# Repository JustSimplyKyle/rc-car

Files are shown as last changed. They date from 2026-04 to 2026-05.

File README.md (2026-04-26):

# Project Description
## tl;dr
a esp-32 powered rc-car, with a step-motor serving as its primary transmission force, using belt wheels for synchronzied left-right wheel, utilizing a mg996r for turning curcuits, displaying all infos on a 128x64 oled display, finally using 3d-printed parts for the car assembly

the pcb is designed using KiCad, while we use Rhino for 3d modeling software.
## why
our school hosted a simple car competition, a really simple one where there's just TT-motors wired to a wireless controller.
my friend and i had so much issues with that car, that we decided we want to make a new-and-improved:tm: version of it!
## wiring diagarm
## screenshots
|  |  |
| :---: | :---: |
| *(pcb layout)* | *(3d view)* |

| Image | Description |
| :---: | :--- |
|  | *(schematic)* |

# Project Structure
the root of the project contains the setup of the firmware, written in esp32-rust.
- `src/bin` - the actual production code for the esp32
- `src/motor` - all the motor control codes are extraplated in here, with mostly complete compile time checking so that timer usage aren't checked at runtime
- `src/ps2.rs & src/ps2_controller_task.rs` - the controller reception api
- `setup` - the pcb & schemcatic(kicad)
- `3d_models` - the 3d models

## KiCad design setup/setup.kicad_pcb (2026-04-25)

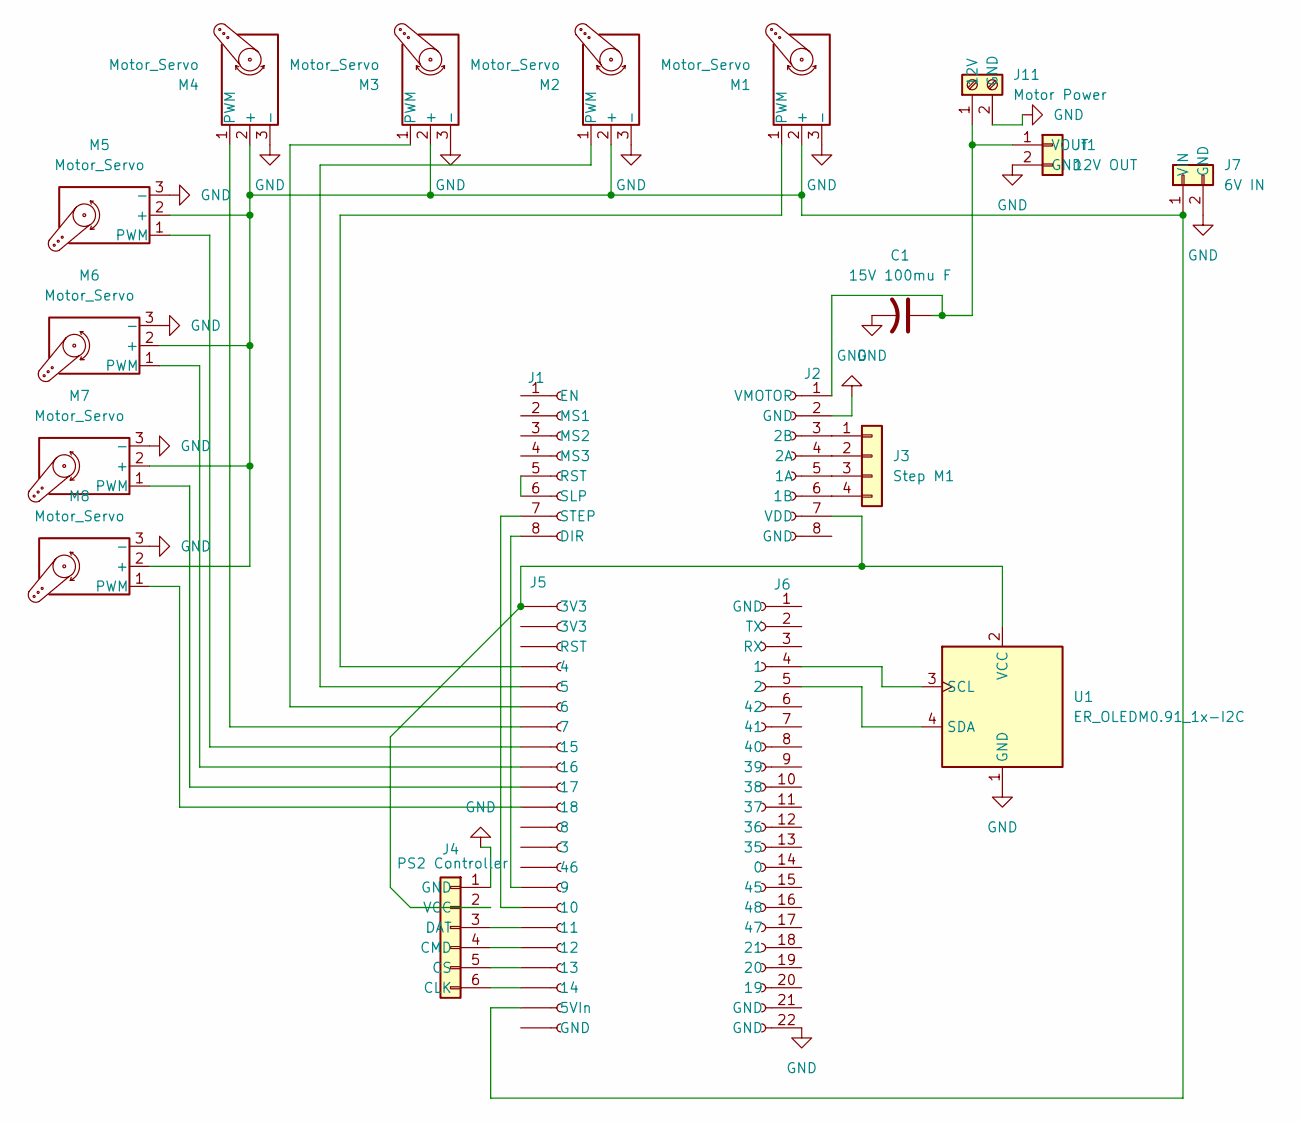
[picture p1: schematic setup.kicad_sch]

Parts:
C1: 15V 100mu F; C_Radial_D10.0mm_H12.5mm_P5.00mm
J1, J2: Conn_01x08_Socket; PinSocket_1x08_P2.54mm_Vertical
J3: Step M1; JST_PH_B4B-PH-K_1x04_P2.00mm_Vertical
J4: PS2 Controller; JST_PH_B6B-PH-K_1x06_P2.00mm_Vertical
J5, J6: Conn_01x22_Socket; PinSocket_1x22_P2.54mm_Vertical
J7: 6V IN; JST_VH_B2P-VH-FB-B_1x02_P3.96mm_Vertical
J11: Motor Power; JST_VH_B2P-VH-FB-B_1x02_P3.96mm_Vertical
Jf1: 12V OUT; JST_VH_B2P-VH-FB-B_1x02_P3.96mm_Vertical
M1, M2, M3, M4, M5, M6, M7, M8: Motor_Servo; JST_PH_B3B-PH-K_1x03_P2.00mm_Vertical
U1: ER_OLEDM0.91_1x-I2C; JST_XH_S4B-XH-A-1_1x04_P2.50mm_Horizontal

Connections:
GND: C1.2, J2.2 (GND), J4.1 (GND), J6.22 (GND), J7.2 (GND), J11.2 (GND), Jf1.2 (GND), M1.3 (-), M2.3 (-), M3.3 (-), M4.3 (-), M5.3 (-), M6.3 (-), M7.3 (-), M8.3 (-), U1.1 (GND)
unnamed: J1.8 (DIR), J5.15 (9)
unnamed: J1.5 (RST), J1.6 (SLP)
unnamed: J1.7 (STEP), J5.16 (10)
unnamed: J2.5 (1A), J3.3
unnamed: J2.6 (1B), J3.4
unnamed: J2.4 (2A), J3.2
unnamed: J2.3 (2B), J3.1
unnamed: J2.7 (VDD), J4.2 (VCC), J5.1 (3V3), U1.2 (VCC)
unnamed: J4.6 (CLK), J5.20 (14)
unnamed: J4.4 (CMD), J5.18 (12)
unnamed: J4.5 (CS), J5.19 (13)
unnamed: J4.3 (DAT), J5.17 (11)
unnamed: J5.21 (5VIn), J7.1 (VIN), M1.2 (+), M2.2 (+), M3.2 (+), M4.2 (+), M5.2 (+), M6.2 (+), M7.2 (+), M8.2 (+)
unnamed: J5.8 (15), M5.1 (PWM)
unnamed: J5.9 (16), M6.1 (PWM)
unnamed: J5.10 (17), M7.1 (PWM)
unnamed: J5.11 (18), M8.1 (PWM)
unnamed: J6.4 (1), U1.3 (SCL)
unnamed: J6.5 (2), U1.4 (SDA)
unnamed: C1.1, J2.1 (VMOTOR), J11.1 (12V), Jf1.1 (VOUT)
unnamed: J5.4, M1.1 (PWM)
unnamed: J5.5, M2.1 (PWM)
unnamed: J5.6, M3.1 (PWM)
unnamed: J5.7, M4.1 (PWM)

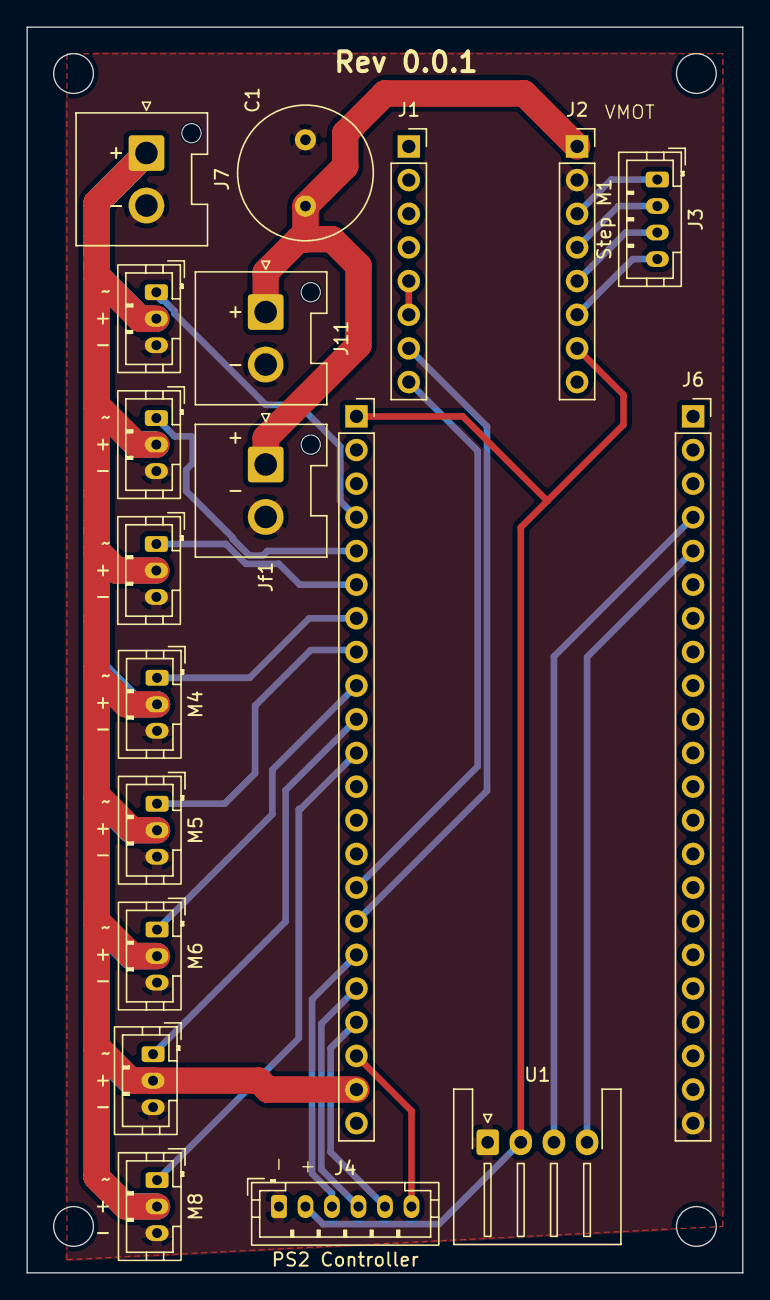
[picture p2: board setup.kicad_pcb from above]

Board: 4 copper layers, 54.0 x 94.0 mm, 19 parts (0 on the bottom side), 25 nets.

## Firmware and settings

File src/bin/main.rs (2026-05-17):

#![no_std]
#![feature(impl_trait_in_assoc_type, type_alias_impl_trait)]
#![no_main]

extern crate alloc;
extern crate rc_car;

use cobs::CobsDecoder;
use core::fmt::Write;
use defmt::error;
use defmt::warn;
use embassy_sync::blocking_mutex::raw::NoopRawMutex;
use embassy_sync::channel::Sender;
use embassy_sync::watch::Watch;
use embassy_time::Duration;
use esp_hal::interrupt::software::SoftwareInterruptControl;
use esp_hal::system::Stack;
use esp_hal::Async;
use esp_radio::esp_now::BROADCAST_ADDRESS;
use heapless::String;

use embedded_hal_compat::ReverseCompat;

use defmt::info;
use esp_hal::i2c::master::Config as I2cConfig;
use esp_hal::i2c::master::I2c;
use esp_hal::time::Rate;

use sh1106::{prelude::*, Builder};

use embassy_executor::Spawner;
use embassy_futures::select::{self, select};
use embassy_sync::blocking_mutex::raw::CriticalSectionRawMutex;
use embassy_time::Timer;
use embedded_graphics::{
    mono_font::{ascii::FONT_5X8, MonoTextStyleBuilder},
    pixelcolor::BinaryColor,
    prelude::Point,
    prelude::*,
    text::{Baseline, Text},
};
use esp_backtrace as _;
use esp_hal::ledc::{self, Ledc};
use esp_hal::{clock::CpuClock, delay::Delay, timer::timg::TimerGroup};
use esp_println as _;
use esp_rtos::start_second_core_with_stack_guard_offset;
use rc_car::motor::{self, ServoCmd};
use rc_car::ps2::Ps2Controller;
use rc_car::ps2_controller_task::PS2_GAMEPAD;
use static_cell::{make_static, StaticCell};

use defmt::println;

esp_bootloader_esp_idf::esp_app_desc!();

#[derive(Clone, Copy, Default)]
struct DisplayState {
    angles: [u32; 5],
}

#[repr(C)]
#[derive(Debug, Default, Copy, Clone)]
pub struct uni_gamepad_t {
    pub dpad: u8,
    pub axis_x: i32,
    pub axis_y: i32,
    pub axis_rx: i32,
    pub axis_ry: i32,
    pub brake: i32,
    pub throttle: i32,
    pub buttons: u16,
    pub misc_buttons: u8,
    pub gyro: [i32; 3usize],
    pub accel: [i32; 3usize],
}

impl uni_gamepad_t {
    pub fn pressed(&self, btn: Button) -> bool {
        match btn {
            Button::Dpad(dpad_direction) => {
                let id = match dpad_direction {
                    DpadDirection::Up => DPAD_UP,
                    DpadDirection::Down => DPAD_DOWN,
                    DpadDirection::Right => DPAD_RIGHT,
                    DpadDirection::Left => DPAD_LEFT,
                };
                (self.dpad & id) != 0
            }
            Button::Regular(btn) => {
                let id = match btn {
                    RegularButton::A => BUTTON_A,
                    RegularButton::B => BUTTON_B,
                    RegularButton::X => BUTTON_X,
                    RegularButton::Y => BUTTON_Y,
                    RegularButton::L1 => BUTTON_SHOULDER_L,
                    RegularButton::R1 => BUTTON_SHOULDER_R,
                    RegularButton::L2 => BUTTON_TRIGGER_L,
                    RegularButton::R2 => BUTTON_TRIGGER_R,
                    RegularButton::ThumbL => BUTTON_THUMB_L,
                    RegularButton::ThumbR => BUTTON_THUMB_R,
                };

                (self.buttons & id) != 0
            }
        }
    }
    pub fn status(&self) -> heapless::String<128> {
        use core::fmt::Write;
        use heapless::String;

        let mut out: String<128> = String::new();

        // D-Pad
        if self.pressed(Button::Dpad(DpadDirection::Up)) {
            let _ = write!(out, "UP ");
        }
        if self.pressed(Button::Dpad(DpadDirection::Down)) {
            let _ = write!(out, "DOWN ");
        }
        if self.pressed(Button::Dpad(DpadDirection::Left)) {
            let _ = write!(out, "LEFT ");
        }
        if self.pressed(Button::Dpad(DpadDirection::Right)) {
            let _ = write!(out, "RIGHT ");
        }

        // Face buttons + shoulders
        let checks = [
            (Button::Regular(RegularButton::A), "A"),
            (Button::Regular(RegularButton::B), "B"),
            (Button::Regular(RegularButton::X), "X"),
            (Button::Regular(RegularButton::Y), "Y"),
            (Button::Regular(RegularButton::L1), "L1"),
            (Button::Regular(RegularButton::R1), "R1"),
            (Button::Regular(RegularButton::L2), "L2"),
            (Button::Regular(RegularButton::R2), "R2"),
            (Button::Regular(RegularButton::ThumbL), "L3"),
            (Button::Regular(RegularButton::ThumbR), "R3"),
        ];

        for (btn, name) in checks {
            if self.pressed(btn) {
                let _ = write!(out, "{} ", name);
            }
        }

        // Optional: include analog hints (only if meaningful)
        if self.axis_x != 0 || self.axis_y != 0 {
            let _ = write!(out, "| LX:{} LY:{} ", self.axis_x, self.axis_y);
        }
        if self.axis_rx != 0 || self.axis_ry != 0 {
            let _ = write!(out, "| RX:{} RY:{} ", self.axis_rx, self.axis_ry);
        }
        if self.throttle != 0 || self.brake != 0 {
            let _ = write!(out, "| RT:{} LT:{} ", self.throttle, self.brake);
        }

        // Trim trailing space
        let _ = out.pop();

        out
    }
}

enum Button {
    Dpad(DpadDirection),
    Regular(RegularButton),
}

enum DpadDirection {
    Up,
    Down,
    Right,
    Left,
}

enum RegularButton {
    A,
    B,
    X,
    Y,
    L1,
    R1,
    L2,
    R2,
    ThumbL,
    ThumbR,
}

pub const DPAD_UP: u8 = 1;
pub const DPAD_DOWN: u8 = 2;
pub const DPAD_RIGHT: u8 = 4;
pub const DPAD_LEFT: u8 = 8;
pub const BUTTON_A: u16 = 1;
pub const BUTTON_B: u16 = 2;
pub const BUTTON_X: u16 = 4;
pub const BUTTON_Y: u16 = 8;
pub const BUTTON_SHOULDER_L: u16 = 16;
pub const BUTTON_SHOULDER_R: u16 = 32;
pub const BUTTON_TRIGGER_L: u16 = 64;
pub const BUTTON_TRIGGER_R: u16 = 128;
pub const BUTTON_THUMB_L: u16 = 256;
pub const BUTTON_THUMB_R: u16 = 512;

use esp_hal::uart::Uart;

// Capacity of 1: display core always gets the latest state, older frames are dropped.
static DISPLAY_WATCH: Watch<CriticalSectionRawMutex, DisplayState, 1> = Watch::new();

#[esp_rtos::main]
async fn main(spawner: Spawner) -> ! {
    let config = esp_hal::Config::default().with_cpu_clock(CpuClock::max());
    let peripherals = esp_hal::init(config);
    esp_alloc::heap_allocator!(size: 64 * 1024);

    let timg0 = TimerGroup::new(peripherals.TIMG0);
    esp_rtos::start(timg0.timer1);

    Timer::after_secs(1).await;

    let wifi = peripherals.WIFI;
    let esp_radio_ctrl = make_static!(esp_radio::init().unwrap());
    let (mut controller, interfaces) =
        esp_radio::wifi::new(&esp_radio_ctrl, wifi, Default::default()).unwrap();
    controller.set_mode(esp_radio::wifi::WifiMode::Sta).unwrap();
    controller.start().unwrap();

    let mut esp_now = interfaces.esp_now;
    esp_now.set_channel(11).unwrap();

    let ledc = make_static!(Ledc::new(peripherals.LEDC));
    ledc.set_global_slow_clock(ledc::LSGlobalClkSource::APBClk);

    rc_car::timer_config!(Servo, 50, Duty12Bit);
    rc_car::timer_config!(Dc, 20000, Duty8Bit);

    let (mut dc, mut m1, mut m2, mut m3, mut m4, mut m5) =
        motor::ledc_motor::MotorSpawner::new(ledc)
            .spawn_dc_new(
                peripherals.GPIO10,
                peripherals.GPIO42,
                peripherals.GPIO40,
                Dc,
            )
            .spawn_pwm_new(spawner, peripherals.GPIO18, 60, 45, 85, Servo)
            .spawn_pwm_reuse(spawner, peripherals.GPIO15, 0, 10, 180, Servo)
            .spawn_pwm_reuse(spawner, peripherals.GPIO16, 40, 0, 180, Servo)
            .spawn_pwm_reuse(spawner, peripherals.GPIO17, 0, 0, 180, Servo)
            .spawn_pwm_reuse(spawner, peripherals.GPIO7, 80, 80 - 35, 80 + 35, Servo)
            .finish();

    dc.set_duty_percent(50);

    // Ps2Controller::spawn(
    //     peripherals.GPIO14,
    //     peripherals.GPIO13,
    //     peripherals.GPIO12,
    //     peripherals.GPIO11,
    //     Delay::new(),
    //     &spawner,
    // );

    let uart = Uart::new(peripherals.UART0, esp_hal::uart::Config::default())
        .unwrap()
        .with_rx(peripherals.GPIO14)
        .with_tx(peripherals.GPIO13)
        .into_async();

    let gamepad_channel = make_static!(Watch::new());

    spawner
        .spawn(uart_task(uart, gamepad_channel.sender()))
        .unwrap();

    let interrupt = SoftwareInterruptControl::new(peripherals.SW_INTERRUPT);

    // start_second_core_with_stack_guard_offset(
    //     peripherals.CPU_CTRL,
    //     interrupt.software_interrupt0,
    //     interrupt.software_interrupt1,
    //     make_static!(Stack::<32768>::new()),
    //     None,
    //     move || {
    //         let i2c_bus = I2c::new(
    //             peripherals.I2C0,
    //             I2cConfig::default().with_frequency(Rate::from_khz(400)),
    //         )
    //         .unwrap()
    //         .with_scl(peripherals.GPIO1)
    //         .with_sda(peripherals.GPIO2);

    //         let mut display: GraphicsMode<_> = Builder::new()
    //             .with_size(DisplaySize::Display128x32)
    //             .connect_i2c(i2c_bus.reverse())
    //             .into();
    //         display.init().unwrap();

    //         let text_style = MonoTextStyleBuilder::new()
    //             .font(&FONT_5X8)
    //             .text_color(BinaryColor::On)
    //             .build();

    //         let mut buf: String<32> = String::new();
    //         let mut state = DisplayState::default();
    //         let mut recv = DISPLAY_WATCH.receiver().unwrap();

    //         loop {
    //             if let Some(new_state) = recv.try_get() {
    //                 state = new_state;
    //             }

    //             display.clear();

    //             const POSITIONS: [(i32, i32); 5] = [(0, 0), (0, 9), (0, 18), (65, 0), (65, 9)];

    //             for (i, (x, y)) in POSITIONS.iter().enumerate() {
    //                 buf.clear();
    //                 write!(buf, "Servo {}: {}", i + 1, state.angles[i]).unwrap();
    //                 Text::with_baseline(&buf, Point::new(*x, *y), text_style, Baseline::Top)
    //                     .draw(&mut display)
    //                     .unwrap();
    //             }

    //             display.flush().unwrap();

    //             // Natural rate limit: the I2C flush above already takes ~10ms at 400kHz.
    //             // Add a small yield to avoid hammering the bus faster than needed.
    //             // This is a blocking spin on core 1 so we use a simple counter loop
    //             // rather than an async timer.
    //             for _ in 0..10_000u32 {
    //                 core::hint::spin_loop();
    //             }
    //         }
    //     },
    // );

    let mut ticker = embassy_time::Ticker::every(embassy_time::Duration::from_millis(5));

    let mut recv = gamepad_channel.receiver().unwrap();

    loop {
        // let data = esp_now.receive_async().await;
        // let data_slice = data.data();

        // if data_slice.len() >= core::mem::size_of::<uni_gamepad_t>() {
        //     let gp =
        //         unsafe { core::ptr::read_unaligned(data_slice.as_ptr() as *const uni_gamepad_t) };

        //     info!("{}", gp.status());
        // } else {
        //     info!("Received packet too short!");
        // }

        let gp = recv.get().await;
        info!("{}", gp.status());

        let display_state = DisplayState {
            angles: [
                m1.angle().await,
                m4.angle().await,
                m3.angle().await,
                m2.angle().await,
                m5.angle().await,
            ],
        };

        DISPLAY_WATCH.sender().send(display_state);

        Timer::after(Duration::from_millis(5)).await;
    }
}

#[embassy_executor::task]
async fn uart_task(
    mut uart: Uart<'static, Async>,
    sender: embassy_sync::watch::Sender<'static, NoopRawMutex, uni_gamepad_t, 4>,
) {
    const GAMEPAD_SIZE: usize = 56;

    let mut out_buf = [0u8; GAMEPAD_SIZE];
    let mut byte = [0u8; 1];
    let mut decoder = CobsDecoder::new(&mut out_buf);

    loop {
        match uart.read_async(&mut byte).await {
            Err(e) => {
                error!("UART read error: {:?}", e);
                decoder = CobsDecoder::new(&mut out_buf);
                continue;
            }
            Ok(_) => {}
        }

        match decoder.feed(byte[0]) {
            Ok(None) => {
                // info!("state machine");
            } // still accumulating
            Ok(Some(len)) if len == GAMEPAD_SIZE => {
                let gp = unsafe { core::ptr::read(out_buf.as_ptr() as *const uni_gamepad_t) };
                sender.send(gp);

                decoder = CobsDecoder::new(&mut out_buf);
            }
            Ok(Some(len)) => {
                warn!("wrong frame size: {} (expected {})", len, GAMEPAD_SIZE);
                decoder = CobsDecoder::new(&mut out_buf);
            }
            Err(e) => {
                error!("failed to decode error, reason: {}", e);

                decoder = CobsDecoder::new(&mut out_buf);
            }
        }
    }
}

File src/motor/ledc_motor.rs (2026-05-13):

use core::marker::PhantomData;

use defmt::info;
use embassy_executor::{task, Spawner};
use embassy_sync::{
    blocking_mutex::raw::CriticalSectionRawMutex,
    channel::{Receiver, Sender},
    watch,
};
use embedded_hal::pwm::SetDutyCycle;
use esp_hal::{
    gpio::{DriveMode, Level, Output, OutputPin},
    ledc::{
        self,
        channel::{self, Channel, ChannelHW, ChannelIFace},
        timer::{self, LSClockSource, TimerIFace},
        Ledc, LowSpeed,
    },
    time::Rate,
};
use num::range_step;
use static_cell::StaticCell;

use crate::motor::{duty_from_angle, ServoCmd, Speed};

pub struct DCMotor<'a> {
    pub pina: Output<'a>,
    pub pinb: Output<'a>,
    pub pwm: Channel<'a, LowSpeed>,
}

impl<'a> DCMotor<'a> {
    fn new(
        pina: impl OutputPin + 'a,
        pinb: impl OutputPin + 'a,
        pwm: Channel<'a, LowSpeed>,
    ) -> Self {
        Self {
            pina: Output::new(pina, Level::Low, Default::default()),
            pinb: Output::new(pinb, Level::Low, Default::default()),
            pwm,
        }
    }
    pub fn set_duty_percent(&self, duty_percentage: u8) {
        self.pwm.set_duty(duty_percentage).unwrap();
    }
    pub fn go_front(&mut self) {
        self.pina.set_high();
        self.pinb.set_low();
    }
    pub fn go_back(&mut self) {
        self.pina.set_low();
        self.pinb.set_high();
    }
    pub fn stop(&mut self) {
        self.pina.set_low();
        self.pinb.set_low();
    }
}

pub trait TimerConfigTrait {
    const FREQUENCY: u32;
    const DUTY_RESOLUTION: timer::config::Duty;

    fn as_config() -> timer::config::Config<LSClockSource> {
        timer::config::Config {
            frequency: Rate::from_hz(Self::FREQUENCY),
            duty: Self::DUTY_RESOLUTION,
            clock_source: LSClockSource::APBClk,
        }
    }
}
pub type ServoChannel = embassy_sync::channel::Channel<CriticalSectionRawMutex, ServoCmd, 4>;
pub type Watch = embassy_sync::watch::Watch<CriticalSectionRawMutex, u32, 1>;

static TIMER_STORAGE: [StaticCell<ledc::timer::Timer<'static, LowSpeed>>; 4] =
    [const { StaticCell::new() }; _];

static CHANNEL_STORAGE: [StaticCell<ServoChannel>; 8] = [const { StaticCell::new() }; _];
static WATCH_STORAGE: [StaticCell<Watch>; 8] = [const { StaticCell::new() }; _];

#[macro_export]
macro_rules! timer_config {
    ($name:ident, $freq:expr, $duty:ident) => {
        pub struct $name;
        impl rc_car::motor::ledc_motor::TimerConfigTrait for $name {
            const FREQUENCY: u32 = $freq;
            const DUTY_RESOLUTION: esp_hal::ledc::timer::config::Duty =
                esp_hal::ledc::timer::config::Duty::$duty;
        }
    };
}

pub struct End;
pub struct Cons<Head, Tail>(PhantomData<Head>, Tail);

// TimerList node — stores the actual timer ref at runtime
pub struct TimerEntry<Config, Tail> {
    timer: &'static timer::Timer<'static, LowSpeed>,
    tail: Tail,
    _config: PhantomData<Config>,
}

pub trait Contains<T, Index> {}

// Base: T is at head
impl<T, Tail> Contains<T, End> for TimerEntry<T, Tail> {}

// Recursive: T is in tail
impl<T, Index, Head, Tail> Contains<T, Cons<Index, ()>> for TimerEntry<Head, Tail> where
    Tail: Contains<T, Index>
{
}

pub trait FindTimer<Config, Index> {
    fn get_timer(&self) -> &'static timer::Timer<'static, LowSpeed>;
}

// Base: Config at head
impl<Config, Tail> FindTimer<Config, End> for TimerEntry<Config, Tail> {
    fn get_timer(&self) -> &'static timer::Timer<'static, LowSpeed> {
        self.timer
    }
}

// Recursive: Config in tail
impl<Config, Head, Tail, Index> FindTimer<Config, Cons<Index, ()>> for TimerEntry<Head, Tail>
where
    Tail: FindTimer<Config, Index>,
{
    fn get_timer(&self) -> &'static timer::Timer<'static, LowSpeed> {
        self.tail.get_timer()
    }
}

pub trait ReuseTimer<Config, Index> {
    fn get_timer(&self) -> &'static timer::Timer<'static, LowSpeed>;
}

impl<Config, Index, List> ReuseTimer<Config, Index> for List
where
    List: FindTimer<Config, Index>,
{
    fn get_timer(&self) -> &'static timer::Timer<'static, LowSpeed> {
        FindTimer::<Config, Index>::get_timer(self)
    }
}

// Case 2: Config not in list — allocate new slot, list grows
pub trait AllocTimer<Config> {
    type Output;
    fn alloc(
        self,
        ledc: &'static Ledc<'static>,
        slot: usize,
    ) -> (&'static timer::Timer<'static, LowSpeed>, Self::Output);
}

// Base: empty list
impl<Config: TimerConfigTrait> AllocTimer<Config> for End {
    type Output = TimerEntry<Config, End>;

    fn alloc(
        self,
        ledc: &'static Ledc<'static>,
        slot: usize,
    ) -> (&'static timer::Timer<'static, LowSpeed>, Self::Output) {
        let hw = ledc.timer::<LowSpeed>(idx_to_timer(slot));
        let timer_ref = TIMER_STORAGE[slot].init(hw);
        timer_ref.configure(Config::as_config()).unwrap();
        info!("Configured timer with freq {}", Config::FREQUENCY);
        (
            timer_ref,
            TimerEntry {
                timer: timer_ref,
                tail: End,
                _config: PhantomData,
            },
        )
    }
}

fn idx_to_timer(s: usize) -> timer::Number {
    match s {
        0 => timer::Number::Timer0,
        1 => timer::Number::Timer1,
        2 => timer::Number::Timer2,
        3 => timer::Number::Timer3,
        _ => unreachable!(),
    }
}

// Recursive: skip head, alloc into tail
impl<Config: TimerConfigTrait, Head, Tail> AllocTimer<Config> for TimerEntry<Head, Tail>
where
    Tail: AllocTimer<Config>,
{
    type Output = TimerEntry<Head, <Tail as AllocTimer<Config>>::Output>;

    fn alloc(
        self,
        ledc: &'static Ledc<'static>,
        slot: usize,
    ) -> (&'static timer::Timer<'static, LowSpeed>, Self::Output) {
        let (timer, new_tail) = self.tail.alloc(ledc, slot);
        (
            timer,
            TimerEntry {
                timer: self.timer,
                tail: new_tail,
                _config: PhantomData,
            },
        )
    }
}

pub trait HasRoom {}
impl HasRoom for End {}
impl<H, T> HasRoom for TimerEntry<H, T> where T: HasRoom2 {}

trait HasRoom2 {}
impl HasRoom2 for End {}
impl<H, T> HasRoom2 for TimerEntry<H, T> where T: HasRoom3 {}

trait HasRoom3 {}
impl HasRoom3 for End {}
impl<H, T> HasRoom3 for TimerEntry<H, T> where T: HasRoom4 {}

trait HasRoom4 {}
impl HasRoom4 for End {}

pub trait TimerCount {
    const COUNT: usize;
}
impl TimerCount for End {
    const COUNT: usize = 0;
}
impl<H, T: TimerCount> TimerCount for TimerEntry<H, T> {
    const COUNT: usize = 1 + T::COUNT;
}

pub struct MotorSpawner<'a, Motors, Timers> {
    ledc: &'a Ledc<'a>,
    motors: Motors,
    timers: Timers,
}

pub struct PwmMotor<'a> {
    sender: Sender<'a, CriticalSectionRawMutex, ServoCmd, 4>,
    angle: watch::Receiver<'a, CriticalSectionRawMutex, u32, 1>,
}
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

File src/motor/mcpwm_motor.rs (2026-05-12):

use defmt::info;
use embassy_executor::Spawner;
use embassy_sync::blocking_mutex::raw::CriticalSectionRawMutex;
use embassy_sync::channel::{self, Receiver, Sender};
use embassy_sync::mutex::Mutex;
use embassy_time::{Duration, Instant};
use embedded_hal::pwm::SetDutyCycle;
use esp_hal::gpio::{Level, Output, OutputPin};
use esp_hal::ledc::{self, timer, Ledc, LowSpeed};
use esp_hal::mcpwm::operator::{PwmPin, PwmPinConfig};
use esp_hal::mcpwm::timer::{PwmWorkingMode, Timer};
use esp_hal::mcpwm::{self, McPwm, PeripheralClockConfig, PwmPeripheral};
use esp_hal::peripherals::MCPWM0;
use esp_hal::time::Rate;
use num::range_step;
use static_cell::make_static;
use static_cell::StaticCell;

use core::convert::Infallible;
use core::marker::PhantomData;

use crate::motor::{duty_from_angle, ServoCmd, Speed};

const CHANNEL_SIZE: usize = 4;

pub enum ErasedPwmPin<'d, PWM: PwmPeripheral> {
    Op0(PwmPin<'d, PWM, 0, true>),
    Op1(PwmPin<'d, PWM, 1, true>),
    Op2(PwmPin<'d, PWM, 2, true>),
}

macro_rules! apply_pwm {
    ($enum_val:expr, $method:ident ( $($arg:expr),* )) => {
        match $enum_val {
            Self::Op0(p) => p.$method($($arg),*),
            Self::Op1(p) => p.$method($($arg),*),
            Self::Op2(p) => p.$method($($arg),*),
        }
    };
}

impl<'d, PWM: PwmPeripheral> ErasedPwmPin<'d, PWM> {
    fn set_timestamp(&mut self, timestamp: u16) {
        apply_pwm!(self, set_timestamp(timestamp));
    }
    fn set_duty_cycle_percent(&mut self, percent: u8) -> Result<(), Infallible> {
        apply_pwm!(self, set_duty_cycle_percent(percent))
    }
    fn period(&self) -> u16 {
        apply_pwm!(self, period())
    }
    const fn operator_index(&self) -> usize {
        match self {
            ErasedPwmPin::Op0(_) => 0,
            ErasedPwmPin::Op1(_) => 1,
            ErasedPwmPin::Op2(_) => 2,
        }
    }
}

/// Associates a motor type with per-operator timer config.
/// `MAPPINGS[i]` = (period_ticks, frequency) for operator i.
pub trait PwmController<'d, PWM: PwmPeripheral>: Sized {
    const MAPPINGS: [(u16, Rate); 3];

    fn timer_period(operator: usize) -> u16 {
        Self::MAPPINGS[operator].0
    }
    fn timer_frequency(operator: usize) -> Rate {
        Self::MAPPINGS[operator].1
    }

    fn new(pin: ErasedPwmPin<'d, PWM>, spawner: &Spawner, initial_angle: u32) -> Self;
}

// ---------------------------------------------------------------------------
// Servo motor
// ---------------------------------------------------------------------------

pub type ServoMotor = Sender<'static, CriticalSectionRawMutex, ServoCmd, CHANNEL_SIZE>;

static MOTOR_MOVING: Mutex<CriticalSectionRawMutex, ()> = Mutex::new(());

pub async fn servo_motor_loop<PWM: PwmPeripheral>(
    mut initial_angle: u32,
    mut speed: Speed,
    cmd: Receiver<'static, CriticalSectionRawMutex, ServoCmd, CHANNEL_SIZE>,
    mut pwm_pin: ErasedPwmPin<'static, PWM>,
) {
    let mut target_angle = initial_angle;

    info!("Moving motor to initial pos.");

    let _guard = MOTOR_MOVING.lock().await;
    let period = pwm_pin.period();
    pwm_pin.set_timestamp(duty_from_angle(initial_angle.clamp(0, 180), period.into()));
    embassy_time::Timer::after_millis(500).await;
    drop(_guard);

    info!("ending moving motor to initial pos");

    loop {
        match cmd.receive().await {
            ServoCmd::TurnToAngle(new_angle) => target_angle = new_angle,
            ServoCmd::SetSpeed(new_speed) => speed = new_speed,
            ServoCmd::IncrementBy(_) => todo!(),
            ServoCmd::DecrementBy(_) => todo!(),
        }
        let period = pwm_pin.period();

        let diff = target_angle as i32 - initial_angle as i32;

        if diff == 0 {
            continue;
        }

        info!("Moving motor");

        let step = diff.signum();

        for angle in range_step(initial_angle as i32, target_angle as i32, step) {
            pwm_pin.set_timestamp(duty_from_angle(angle.clamp(0, 180) as u32, period.into()));
            match speed {
                Speed::Slow => embassy_time::Timer::after_millis(15).await,
                Speed::Normal => embassy_time::Timer::after_millis(10).await,
                Speed::Fast => embassy_time::Timer::after_millis(5).await,
                Speed::Instant => {}
                Speed::Custom(time) => embassy_time::Timer::after(time).await,
            }
        }

        initial_angle = target_angle;

        info!("finished moving");
    }
}
pub enum StepCmd {
    Forward { duty: u8 },
    Backward { duty: u8 },
    Stop,
}

pub async fn step_motor_loop<PWM: PwmPeripheral>(
    cmd: Receiver<'static, CriticalSectionRawMutex, StepCmd, CHANNEL_SIZE>,
    mut motor: CDStepMotor<'static, PWM>,
) {
    loop {
        match cmd.receive().await {
            StepCmd::Forward { duty } => {
                motor.set_duty_cycle_percent(duty);
                motor.go_forward();
            }
            StepCmd::Backward { duty } => {
                motor.set_duty_cycle_percent(duty);
                motor.go_backward();
            }
            StepCmd::Stop => {
                motor.stop();
            }
        }
    }
}

macro_rules! impl_servo_motor_task {
    ($pwm:ty, $task_name:ident) => {
        #[embassy_executor::task(pool_size = 3)]
        pub async fn $task_name(
            initial_angle: u32,
            speed: Speed,
            cmd: Receiver<'static, CriticalSectionRawMutex, ServoCmd, CHANNEL_SIZE>,
            pwm_pin: ErasedPwmPin<'static, $pwm>,
        ) {
            servo_motor_loop(initial_angle, speed, cmd, pwm_pin).await;
        }

        impl PwmController<'static, $pwm> for ServoMotor {
            const MAPPINGS: [(u16, Rate); 3] = [
                (20_000, Rate::from_hz(50)),
                (20_000, Rate::from_hz(50)),
                (20_000, Rate::from_hz(50)),
            ];
            fn new(
                pin: ErasedPwmPin<'static, $pwm>,
                spawner: &Spawner,
                initial_angle: u32,
            ) -> Self {
                static CHANNELS: [StaticCell<
                    channel::Channel<CriticalSectionRawMutex, ServoCmd, CHANNEL_SIZE>,
                >; 3] = [StaticCell::new(), StaticCell::new(), StaticCell::new()];

                let op_idx = pin.operator_index();
                info!("operation index: {}", op_idx);
                let channel = CHANNELS[op_idx].init(channel::Channel::new());

                spawner
                    .spawn($task_name(
                        initial_angle,
                        Speed::Fast,
                        channel.receiver(),
                        pin,
                    ))
                    .unwrap();
                channel.sender()
            }
        }
    };
}
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

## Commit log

2026-04-01 feat: ledc except mcpwm
2026-04-05 feat: eros inspired timer based container
2026-04-21 feat: step motor
2026-04-22 feat: include pcb
    [setup.kicad_pcb, setup.kicad_sch]
2026-04-23 feat: add oled(pcb)
    [setup.kicad_pcb, setup.kicad_sch]
2026-04-23 feat: separate step motor into module
2026-04-23 feat: re-order pcb
    [setup.kicad_pcb, setup.kicad_sch]
2026-04-23 feat: swap below upper
    [setup.kicad_pcb]
2026-04-23 feat: use two-layer routing for motor voltages
    [setup.kicad_pcb, setup.kicad_sch]
2026-04-23 feat: attempt to add copper fill for servo vins
    [setup.kicad_pcb]
2026-04-23 fix: route gnd
    [setup.kicad_pcb]
2026-04-23 feat: make board jlcpcb compatiable
    [setup.kicad_pcb, setup.kicad_sch]
2026-04-25 feat: add jlcpcb & fix vh connection
    [setup.kicad_pcb, setup.kicad_sch]
2026-04-27 feat: make ledc motor accsept servo too
2026-05-08 feat: make direction switchig in step motor possible
2026-05-09 feat: make dc-motor multi-variable control
2026-05-10 refactor: refactor so that ledc and mcpwm have proper structure
2026-05-12 feat: add servo & display
2026-05-12 refactor: make `PwmMotor` control angles too
2026-05-12 feat: move i2c bus oled into second core
2026-05-13 fix: make initial angle clamp to min and max
    [ledc_motor.rs, main.rs]
2026-05-17 feat: use uart instead of espnow
